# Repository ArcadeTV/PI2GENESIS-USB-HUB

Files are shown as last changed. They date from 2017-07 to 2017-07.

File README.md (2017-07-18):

# PI2GENESIS-USB-HUB

PCB for placing a RaspberryPi3 into Nerd Block's Genesis USB Hub and getting 15KHz RGB Video + CompositeSync out of it.

## What does it do, exactly?

Connects to a Raspberry PI 3(b) inside the housing of Arcadeblock(Nerdblock) Genesis USB Hub and turns it into a mini-videogame-system.
Video-Output is 15KHz-RGB. Needs configuration settings to output correct video. (Like/same as Pi2Scart or Pi2Jamma)
Uses the original USB-sockets from the USB-Hub's PCB.

## PCB Specs and getting hands on the boards
I can recommend itead.cc for pcb manufacturing. Either export the GERBER files from EAGLE using the files that I provided or wait until I finished writing this readme and find them inside the repository.
```
### PCB SPECS:
----------------
* 10.0 x 5.0 cm
* 1.2 mm Thickness
* Surface: HASL
```

### Installing

```
I made a PDF with an installation guide.
```
* desolder original USB-sockets and install them on the pcb
* solder PCB to GPIO-pins
* connect usb-pins with cables (D+ and D- Lines 1-4)
* connect usb-power-pin to one of the usb-sockets on the PI
* connect AUDIO from PI to SND-L and SND-R pins
* connect VIDEO-OUT to AV-Socket
* connect POWER and GND from PSU to 5V-IN
* connect POWER and GND from 5V-OUT to PI-Power-Input (miniUSB-port)
* when AUDIO has noise, use a groundloop-isolator between the connetction

## Additional Modding of the Hub's case

* DC-Power-Input (5V)
* Video-Out via 8-Pin-MiniDIN Socket (I also provided files for a convenient adapter)
* optional separate H- and V-Sync via dedicated cinch-sockets and cinch-to-bnc cables for studio monitors/PVM

## On the Software-Side

Search the web for GertVGA66, PI2SCART, PI2JAMMA and similar Projects. Once your PI is configured to output video through the GPIO port, the built-in DAC on the PCB will produce 15KHz RGB Video.

## Built With

* EAGLE (https://www.autodesk.de/products/eagle/overview)

## Versioning

This is likely the first and last release of this project.

## Authors

* **Alex Schütz**

## License

This project is licensed under the MIT License - see the [LICENSE.md](LICENSE.md) file for details

## Acknowledgments

* This project is completely UNTESTED!
* Inspiration came from GERT/VGA666 and other Pi2RGB Projects
* Please don't mess with electronics if you have no clue what you're doing!

## Q&A's

* Why did you abandon this project?

-> The USB-hubs are sold out and I have other stuff to care about.

* Why is the Raspberry Pi's sound so bad over the headphone jack?

-> It's because of the PI's limitations regarding analogue sound. Get a USB-Soundcard! Those are dirtcheap and produce very acceptable audio.

* Can I still use HDMI as Video-Output?

-> Sure, but then I suggest you just pass installing this pcb, it will not get you any advantage while using HDMI.

* Man, I love your stuff - Can you please send me a fully loaded pcb because I have 2 left hands and can't solder.

-> Dude, just download the stuff that I release to the public. It usually contains everything you need to order PCBs wherever you want plus information on how to use or install it. Anyways, if you can't solder, sending you a pupulated PCB is like sending you a can, knowing you don't have a can-opener...

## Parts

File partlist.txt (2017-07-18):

Partlist

Exported from PI2GENESIS-HUB_SWITCH.sch at 22.03.17 22:21

EAGLE Version 8.1.0 Copyright (c) 1988-2017 Autodesk, Inc.

Assembly variant:

Part     Value           Device                            Package                           Library  Sheet

BC1      100nF           C0805                             Z0805                             arcadetv 1
BC2      100nF           C0805                             Z0805                             arcadetv 1
C1       220nF           C0805                             Z0805                             arcadetv 1
C2       220nF           C0805                             Z0805                             arcadetv 1
C3       4.7uF           EEEFPJ101UAR_PANASONIC_VFP-SERIES EEEFPJ101UAR_PANASONIC_VFP-SERIES arcadetv 1
C4       4.7uF           EEEFPJ101UAR_PANASONIC_VFP-SERIES EEEFPJ101UAR_PANASONIC_VFP-SERIES arcadetv 1
C5       10uF            EEEFPJ101UAR_PANASONIC_VFP-SERIES EEEFPJ101UAR_PANASONIC_VFP-SERIES arcadetv 1
C6       10uF            EEEFPJ101UAR_PANASONIC_VFP-SERIES EEEFPJ101UAR_PANASONIC_VFP-SERIES arcadetv 1
IC1      4070D           4070D                             SO14                              40xx     1
IC2      ST662A          ST662A                            SO-8                              arcadetv 1
R1       499             R-US_R0603                        R0603                             rcl      1
R2       1K              R-US_R0603                        R0603                             rcl      1
R3       2K              R-US_R0603                        R0603                             rcl      1
R4       4K              R-US_R0603                        R0603                             rcl      1
R5       8K              R-US_R0603                        R0603                             rcl      1
R6       16K             R-US_R0603                        R0603                             rcl      1
R7       499             R-US_R0603                        R0603                             rcl      1
R8       1K              R-US_R0603                        R0603                             rcl      1
R9       2K              R-US_R0603                        R0603                             rcl      1
R10      4K              R-US_R0603                        R0603                             rcl      1
R11      8K              R-US_R0603                        R0603                             rcl      1
R12      16K             R-US_R0603                        R0603                             rcl      1
R13      499             R-US_R0603                        R0603                             rcl      1
R14      1K              R-US_R0603                        R0603                             rcl      1
R15      2K              R-US_R0603                        R0603                             rcl      1
R16      4K              R-US_R0603                        R0603                             rcl      1
R17      8K              R-US_R0603                        R0603                             rcl      1
R18      16K             R-US_R0603                        R0603                             rcl      1
R19      120             R-US_R0603                        R0603                             rcl      1
R20      120             R-US_R0603                        R0603                             rcl      1
R22      4K7             R-US_R0603                        R0603                             rcl      1
R23      4K7             R-US_R0603                        R0603                             rcl      1
R29      220             R-US_R0603                        R0603                             rcl      1
U$4      ALPS-SSSU011700 ALPS-SSSU011700                   ALPS-SSSU011700                   arcadetv 1

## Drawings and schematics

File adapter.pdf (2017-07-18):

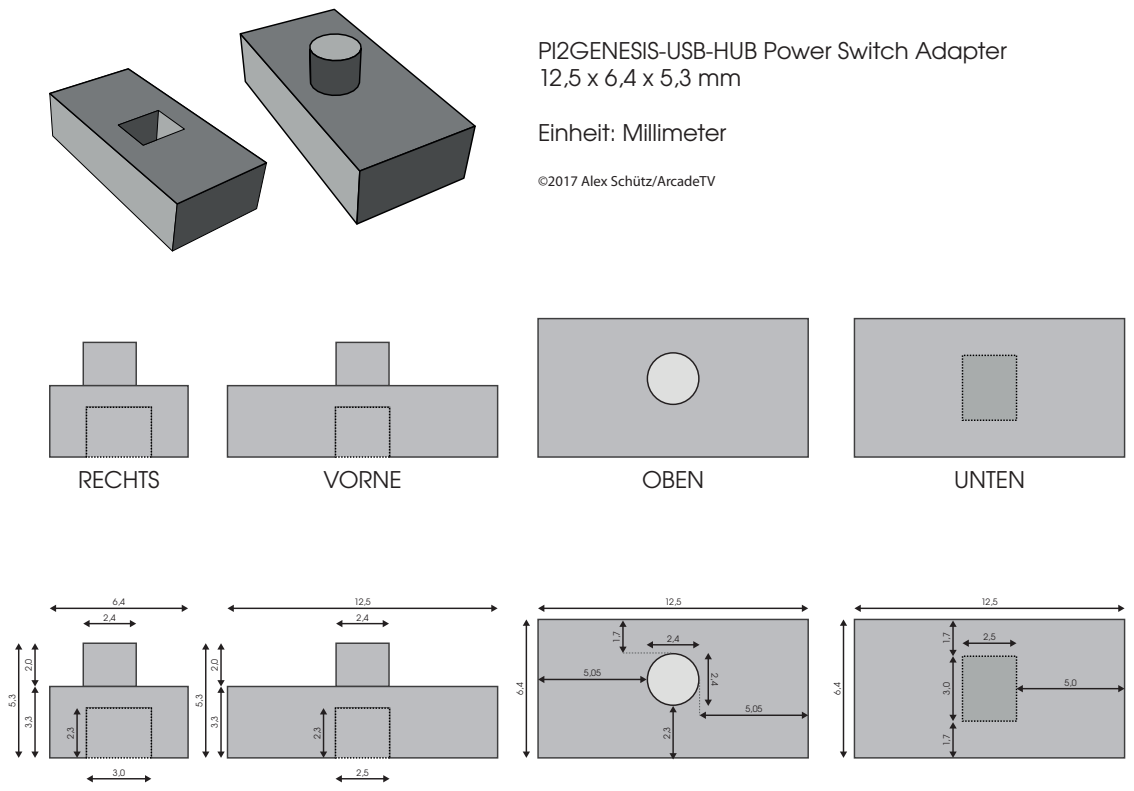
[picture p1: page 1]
RECHTS; VORNE; OBEN; Einheit: Millimeter; UNTEN

PI2GENESIS-USB-HUB Power Switch Adapter

©2017 Alex Schütz/ArcadeTV

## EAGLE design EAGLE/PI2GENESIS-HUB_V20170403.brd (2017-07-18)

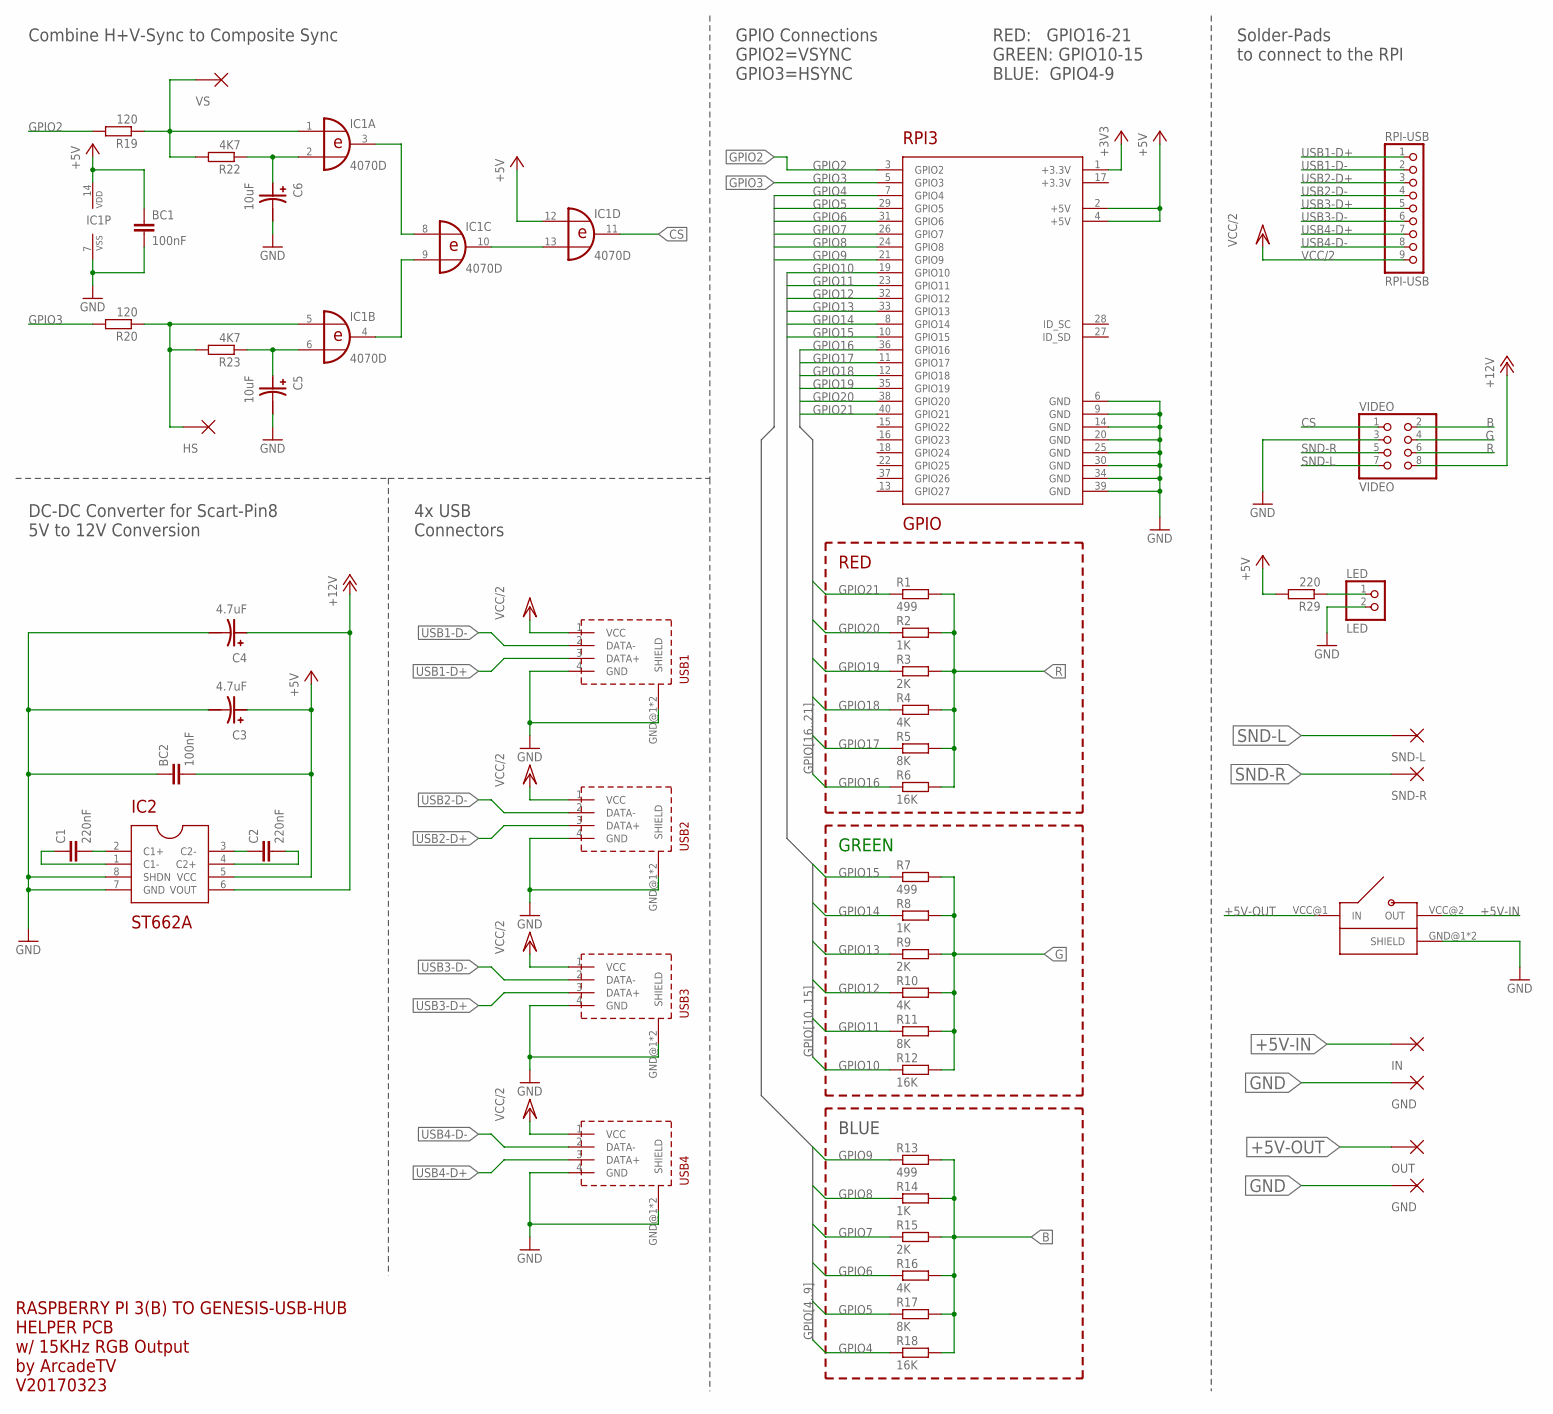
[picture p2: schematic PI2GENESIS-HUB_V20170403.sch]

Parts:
BC1, BC2: 100nF; Z0805
C1, C2: 220nF; Z0805
C3, C4: 4.7uF; EEEFPJ101UAR_PANASONIC_VFP-SERIES
C5, C6: 10uF; EEEFPJ101UAR_PANASONIC_VFP-SERIES
IC1: 4070D; SO14
IC2: ST662A; SO-8
LED: LED; 1X02
PAD1: HS; PADS
PAD2: VS; PADS
R1, R7, R13: 499; Z0805
R2, R8, R14: 1K; Z0805
R3, R9, R15: 2K; Z0805
R4, R10, R16: 4K; Z0805
R5, R11, R17: 8K; Z0805
R6, R12, R18: 16K; Z0805
R19, R20: 120; Z0805
R22, R23: 4K7; Z0805
R29: 220; Z0805
RPI3: GPIO; RPI3-GPIO
RPI-USB: RPI-USB; 1X09
U$1: OUT; PADS
U$2: SND-L; PADS
U$3: SND-R; PADS
U$4: ALPS-SSSU011700
U$5: IN; PADS
U$6, U$7: GND; PADS
USB1, USB2, USB3, USB4: USB-GENESIS-HUB
VIDEO: VIDEO; 2X04

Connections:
+3V3: RPI3.1 (+3.3V)
+5V: BC1.1, BC2.2, C3.PLUS (+), IC1.12 (I0), IC1.14 (VDD), IC2.5 (VCC), R29.2, RPI3.2 (+5V), RPI3.4 (+5V)
+5V-IN: U$4.VCC@2 (OUT), U$5.P$1
+5V-OUT: U$1.P$1, U$4.VCC@1 (IN)
+12V: C4.PLUS (+), IC2.6 (VOUT), VIDEO.8
B: R13.2, R14.2, R15.2, R16.2, R17.2, R18.2, VIDEO.2
CS: IC1.11 (O), VIDEO.1
G: R7.2, R8.2, R9.2, R10.2, R11.2, R12.2, VIDEO.4
GND: BC1.2, BC2.1, C3.MINUS (-), C4.MINUS (-), C5.MINUS (-), C6.MINUS (-), IC1.7 (VSS), IC2.7 (GND), IC2.8 (SHDN), LED.2, RPI3.6 (GND), RPI3.9 (GND), RPI3.14 (GND), RPI3.20 (GND), RPI3.25 (GND), RPI3.30 (GND), RPI3.34 (GND), RPI3.39 (GND), U$4.GND@1 (SHIELD), U$4.GND@2 (SHIELD), U$6.P$1, U$7.P$1, USB1.4 (GND), USB1.GND@1 (SHIELD), USB1.GND@2 (SHIELD), USB2.4 (GND), USB2.GND@1 (SHIELD), USB2.GND@2 (SHIELD), USB3.4 (GND), USB3.GND@1 (SHIELD), USB3.GND@2 (SHIELD), USB4.4 (GND), USB4.GND@1 (SHIELD), USB4.GND@2 (SHIELD), VIDEO.3
GPIO2: R19.2, RPI3.3 (GPIO2)
GPIO3: R20.2, RPI3.5 (GPIO3)
GPIO4: R18.1, RPI3.7 (GPIO4)
GPIO5: R17.1, RPI3.29 (GPIO5)
GPIO6: R16.1, RPI3.31 (GPIO6)
GPIO7: R15.1, RPI3.26 (GPIO7)
GPIO8: R14.1, RPI3.24 (GPIO8)
GPIO9: R13.1, RPI3.21 (GPIO9)
GPIO10: R12.1, RPI3.19 (GPIO10)
GPIO11: R11.1, RPI3.23 (GPIO11)
GPIO12: R10.1, RPI3.32 (GPIO12)
GPIO13: R9.1, RPI3.33 (GPIO13)
GPIO14: R8.1, RPI3.8 (GPIO14)
GPIO15: R7.1, RPI3.10 (GPIO15)
GPIO16: R6.1, RPI3.36 (GPIO16)
GPIO17: R5.1, RPI3.11 (GPIO17)
GPIO18: R4.1, RPI3.12 (GPIO18)
GPIO19: R3.1, RPI3.35 (GPIO19)
GPIO20: R2.1, RPI3.38 (GPIO20)
GPIO21: R1.1, RPI3.40 (GPIO21)
unnamed: C1.2, IC2.2 (C1+)
unnamed: C1.1, IC2.1 (C1-)
unnamed: C2.1, IC2.3 (C2-)
unnamed: C2.2, IC2.4 (C2+)
unnamed: LED.1, R29.1
unnamed: IC1.1 (I0), PAD2.P$1, R19.1, R22.2
unnamed: C5.PLUS (+), IC1.6 (I1), R23.1
unnamed: IC1.4 (O), IC1.9 (I1)
unnamed: IC1.10 (O), IC1.13 (I1)
unnamed: IC1.5 (I0), PAD1.P$1, R20.1, R23.2
unnamed: IC1.3 (O), IC1.8 (I0)
unnamed: C6.PLUS (+), IC1.2 (I1), R22.1
R: R1.2, R2.2, R3.2, R4.2, R5.2, R6.2, VIDEO.6
SND-L: U$2.P$1, VIDEO.7
SND-R: U$3.P$1, VIDEO.5
USB1-D+: RPI-USB.1, USB1.3 (DATA+)
USB1-D-: RPI-USB.2, USB1.2 (DATA-)
USB2-D+: RPI-USB.3, USB2.3 (DATA+)
USB2-D-: RPI-USB.4, USB2.2 (DATA-)
USB3-D+: RPI-USB.5, USB3.3 (DATA+)
USB3-D-: RPI-USB.6, USB3.2 (DATA-)
USB4-D+: RPI-USB.7, USB4.3 (DATA+)
USB4-D-: RPI-USB.8, USB4.2 (DATA-)
VCC/2: RPI-USB.9, USB1.1 (VCC), USB2.1 (VCC), USB3.1 (VCC), USB4.1 (VCC)

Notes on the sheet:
DC-DC Converter for Scart-Pin8 5V to 12V Conversion
4x USB Connectors
GPIO Connections GPIO2=VSYNC GPIO3=HSYNC
RED
GREEN
BLUE
RED: GPIO16-21 GREEN: GPIO10-15 BLUE: GPIO4-9
Combine H+V-Sync to Composite Sync
RASPBERRY PI 3(B) TO GENESIS-USB-HUB HELPER PCB w/ 15KHz RGB Output by ArcadeTV V20170323
Solder-Pads to connect to the RPI

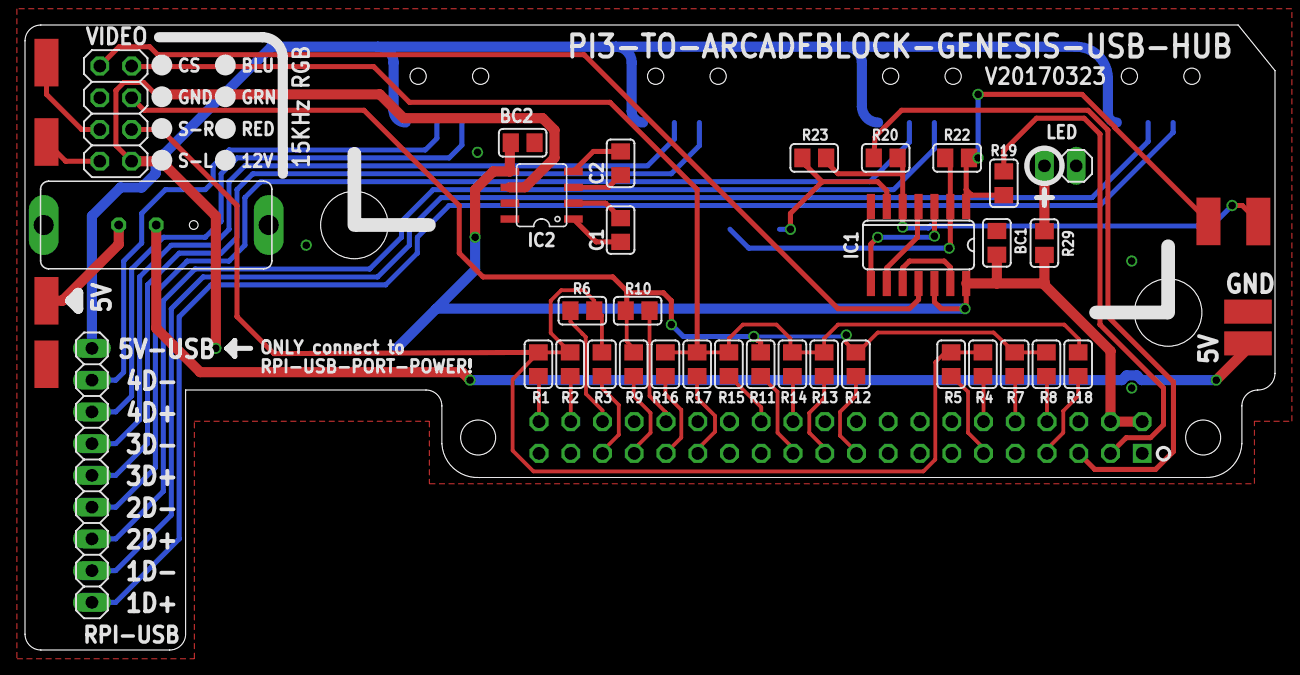
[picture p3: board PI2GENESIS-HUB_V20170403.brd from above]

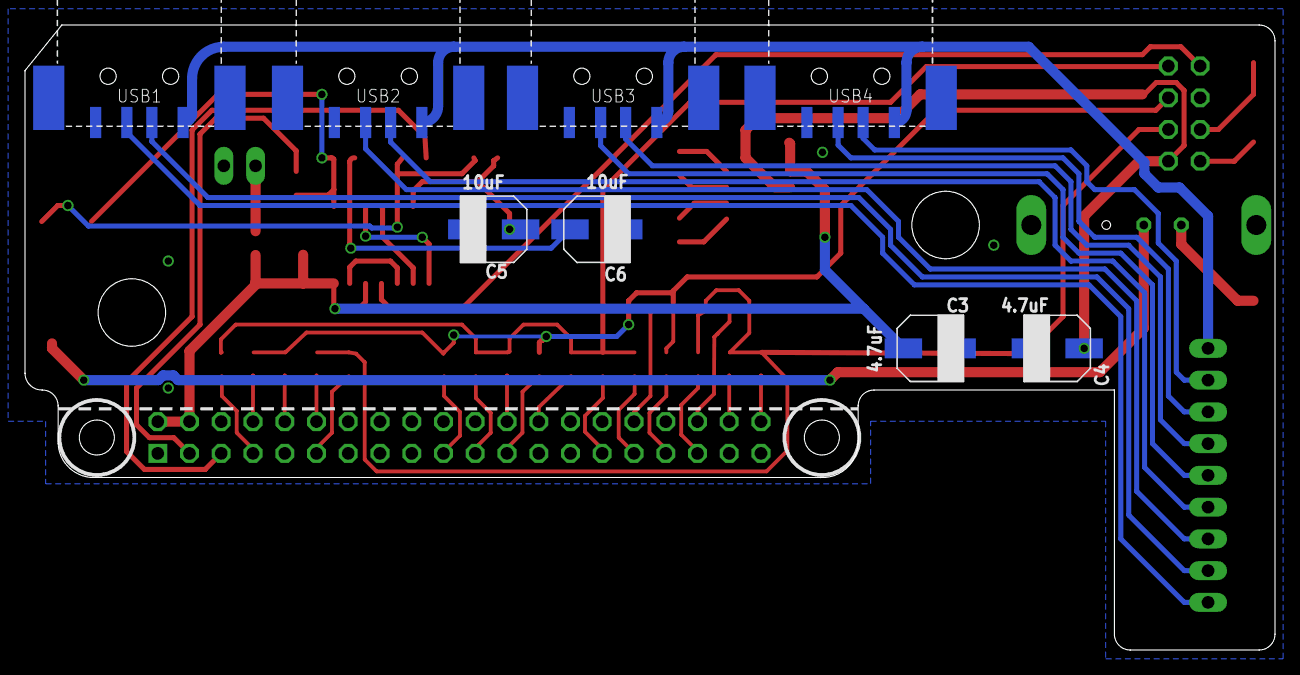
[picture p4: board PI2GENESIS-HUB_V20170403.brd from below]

Board: 2 copper layers, 100.0 x 50.0 mm, 50 parts (9 on the bottom side), 52 nets.

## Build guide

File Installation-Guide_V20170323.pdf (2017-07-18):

# PI2GENESIS-USB-HUB

# Installation

1. Align the PI to the PCB as shown in the picture.
2. Optional: use 2x M3.5 screws to mount the PCBs together.
3. Solder the PCB to the 40 GPIO pins.
4. Install a DC/Power-Socket to the housing.
5. Install an appropriate AV connector to the housing,
such as a miniDIN, DSub-9(VGA) or whatever suits your needs.
6. Connect the positive line from the DC-socket to „5V IN“ on the PCB. Connect the negative line to a GND pad on the PCB.
7. Connect the „5V OUT“ pad to PP1 or PP2 on the PI.
Connect the unused GND pad to PP5 on the PI.
8. Connect the „5V-USB“ pad on the PCB to PP27 on the PI. Connect 1D+ on the PCB to PP43 on the PI.
Connect 1D- on the PCB to PP42 on the PI.
Connect 2D+ on the PCB to PP41 on the PI.
Connect 2D- on the PCB to PP36 on the PI. Connect 3D+ on the PCB to PP47 on the PI. Connect 3D- on the PCB to PP46 on the PI.
Connect 4D+ on the PCB to PP45 on the PI.
Connect 4D- on the PCB to PP44 on the PI.
Don‘t use the original USB-sockets any more, desolder them if you like.
9. Connect Audio through pads „SND-L“ and „SND-R“ on the PCB
to PP25 (left) and PP26 (right) on the PI.
If you have bad audio like humming,
use an isolation transformer or groundloop-breaker circuit.
10. Connect the VIDEO signals from the PCB to your AV-socket. Use SHIELDED cables!!! and connect the shielding to GND! Always connect GNDs to all GND-pins.
11. When using your PI, be aware you need a special config file for correct video (15KHz/RGB) output!

Preparation:

Desolder the 4 USB sockets from the board inside the GENESIS-HUB and install them onto the PCB.

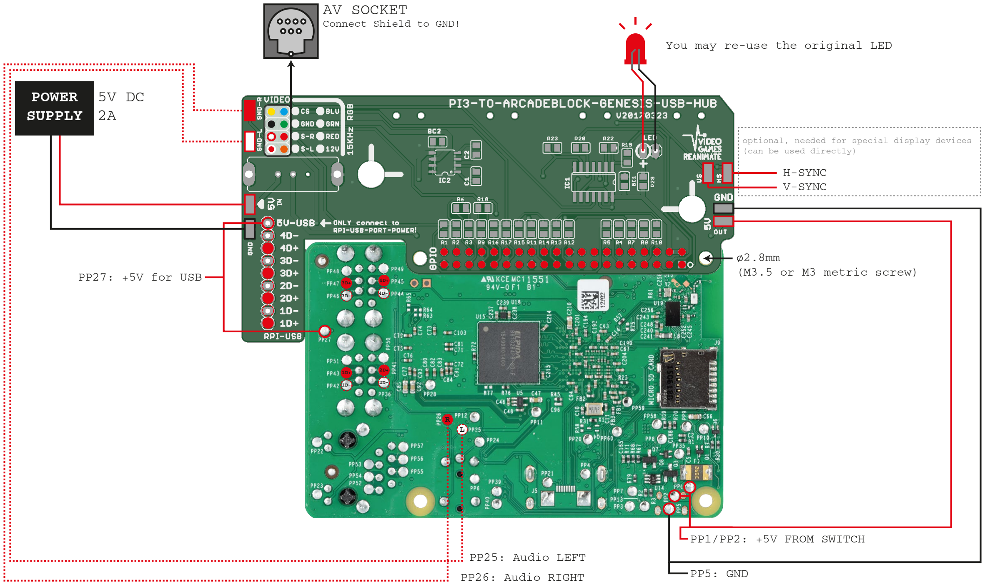
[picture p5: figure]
PP5: GND; PP25: Audio LEFT; PP26: Audio RIGHT; PP27: +5V for USB; AV SOCKET; Connect Shield to GND!; PP1/PP2: +5V FROM SWITCH; ø2.8mm (M3.5 or M3 metric screw); H-SYNC; You may re-use the original LED; (can be used directly); V-SYNC; POWER SUPPLY

optional, needed for special display devices

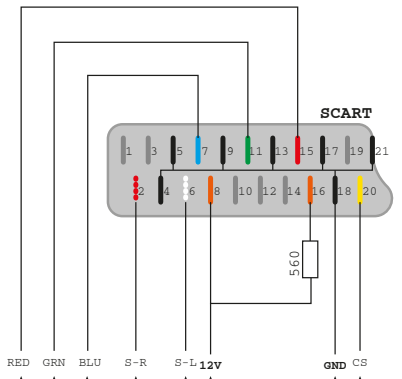
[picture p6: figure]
RED GRN BLU; GND CS; SCART

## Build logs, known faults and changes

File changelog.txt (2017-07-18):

CHANGELOG

22.03.2017
-Added Power Switch
-Added Pads for 5V-IN and OUT, order is PSU->SWITCH->PI-DC-IN->GPIO->PCB
